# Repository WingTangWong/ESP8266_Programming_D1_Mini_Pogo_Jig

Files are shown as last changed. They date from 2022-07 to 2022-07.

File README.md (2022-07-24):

# ESP8266 Programming D1 Mini Pogo Jig V2

This board makes use of a WemosD1Mini (ESP8266 version) board as a USB->SERIAL adapter to flash
ESP-12 modules via POGO pins.

* [Eagle Files](EAGLE)
* [KiCAD Files](KICAD)
* [Gerber/Drill Production Files](PRODUCTION_FILES)
* [Gerber/Drill Production File ZIP](PRODUCTION_FILES/ESP12_Harness.zip)

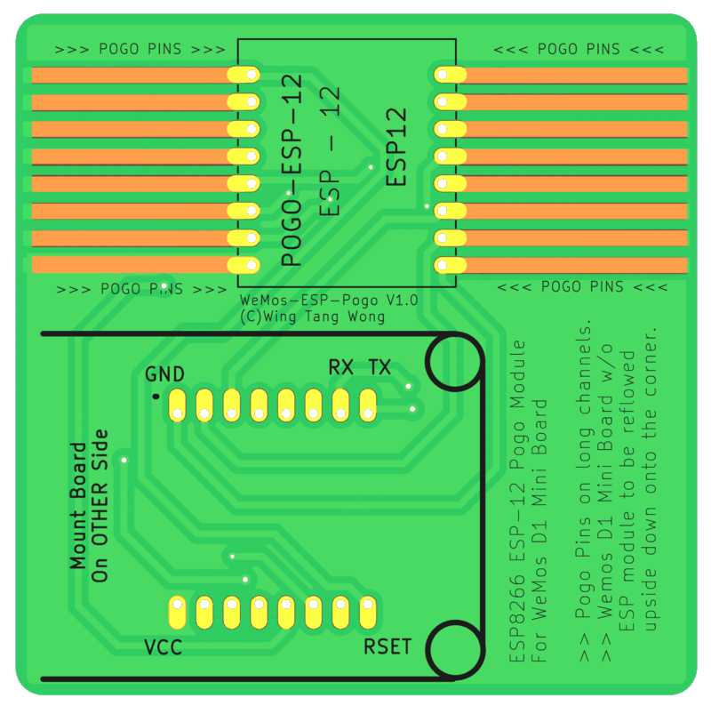
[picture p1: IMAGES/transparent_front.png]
Front

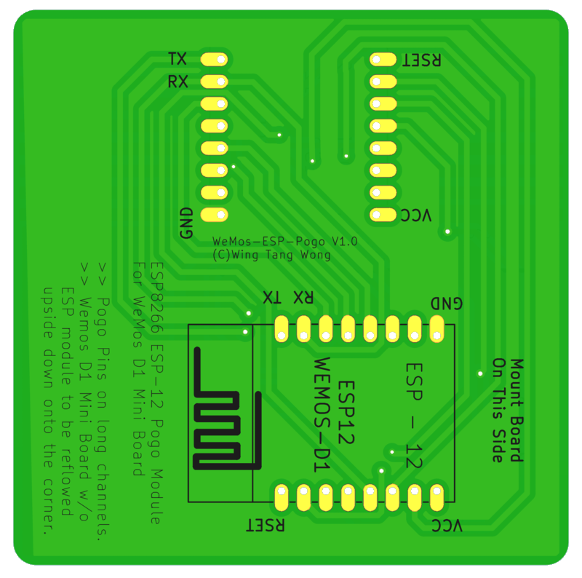
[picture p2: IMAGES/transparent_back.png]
Back


# Version 2 - Changelog

* Imported [Eagle CAD](EAGLE) files into [KiCAD 6.x](KICAD) and did some cleanup:
  * Rerouted some paths so that they weren't right on top of each other.
  * Fixed an import bug to make sure that the pogo traces show up.
  * Fixed the silkscreen on some footprints so that DRC passes without warnings.
* Exported Gerber and Drill files for the Version 2 design from KiCAD: [Production Files](PRODUCTION_FILES) / [Production File ZIP](PRODUCTION_FILES/ESP12_Harness.zip)

# Original Version 1 - Changelog

* Originally Designed in [Eagle CAD](EAGLE)
* Circuit works, but traces were pretty close together
* The masking configs don't port to KiCad very well, so creating a version 2 that is done using [KiCAD](KICAD)
* Silkscreens are all over the place. lulz.

This is a board designed to take a WeMos D1 Mini board(with the ESP module removed) and use it as a USB interface with built-in reset/flash
functionality for bare ESP8266 modules similar to the ESP-12 units.

The PCB was drawn up in Eagle and I have successfully gotten them manufactured through OshPark.

They are designed to be used with Pogo pins. I STRONGLY recommend the mushroom head type. 

The D1 Mini board is to be mated to the PCB in a manner similar to ball grid array: add solder to the pads where the ESP module was to give it a bump.

Rest the board on the PCB within the outline with the bumps facing their matching set of pads and heat from below with a hot air gun. When the solder
melts, the boards will come together. Presuming no bridges, you should be good to go.

# Gotchas

* Don't install the pogo pins too far in. Otherwise, you'll never get the ESP module installed.
* Don't get flux or solder onto the pin portion of the pogo pin... this will ruin them.
* Don't use low temp solder paste... tried this route and was a PITA.
* You can solder the pogo pins individually... but I had the best luck with 2 runs of solder paste on the end away from the pin side and placing the pins in place and using hot air to reflow the solder. This works great.

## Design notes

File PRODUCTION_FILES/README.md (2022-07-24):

# Gerber and Drill files for the ESP12 board.

* Generated from KiCAD files

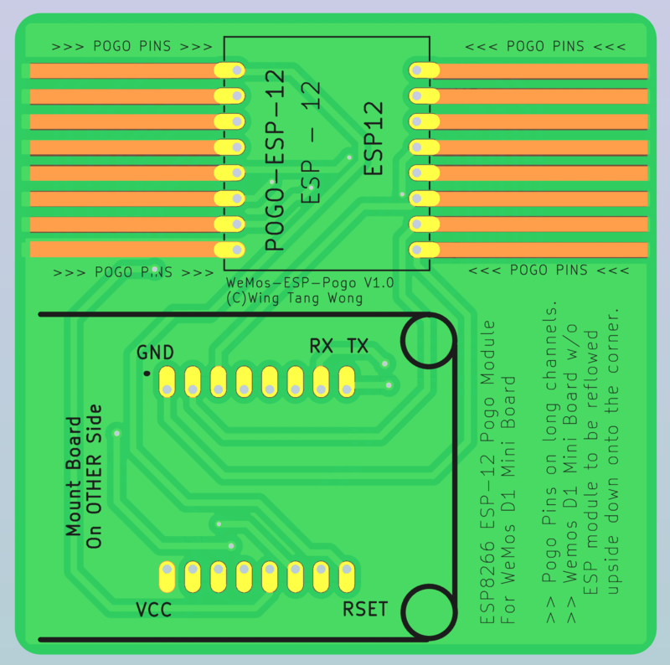
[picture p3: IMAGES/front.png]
PCB Front

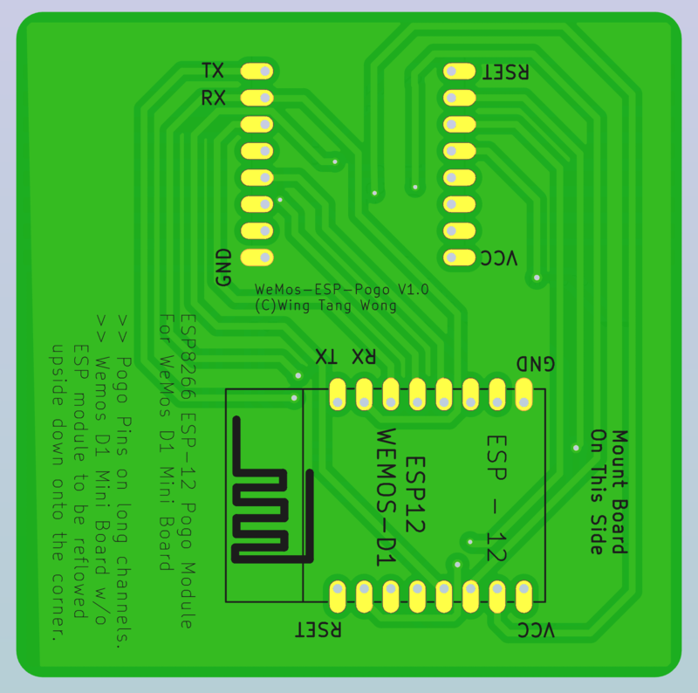
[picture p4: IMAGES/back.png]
PCB Back


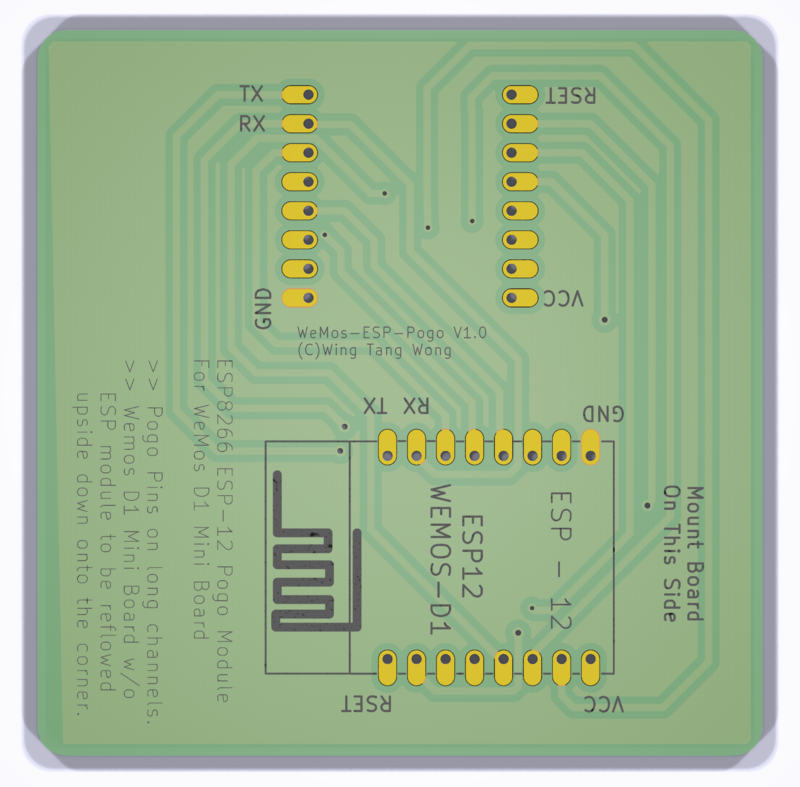
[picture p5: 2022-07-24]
IMAGES/back_3d.png

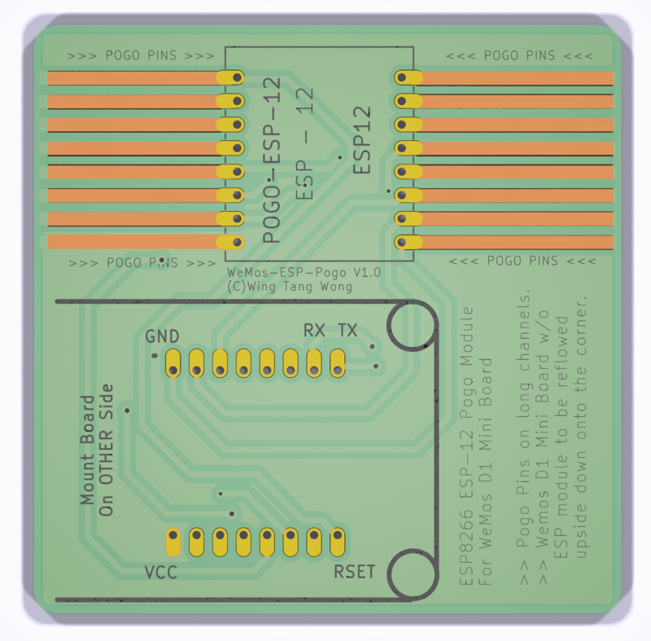
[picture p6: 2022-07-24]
IMAGES/front_3d.png

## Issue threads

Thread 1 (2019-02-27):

Gerber version of the board

adrianmihalko, 2019-02-27:
Somebody please can convet Eagle .brd file into Gerber project? Many PCB services are accepting only this format.

WingTangWong, 2022-07-24:
Hey hey, resolving this issue. I've been migrating other stuff to KiCad, finally got around to this one. You can find the Gerber and Drill files in the [Production Files folder.](https://github.com/WingTangWong/ESP8266_Programming_D1_Mini_Pogo_Jig/tree/main/PRODUCTION_FILES)

Closed 2022-07-24.

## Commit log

2017-02-26 Adding brd and sch files
    [ESP12_Harness.brd, ESP12_Harness.sch]
2022-07-24 Moved Eagle CAD files to their own folder
    [ESP12_Harness.brd, ESP12_Harness.sch]
2022-07-24 Adding rendered images of updated board.
2022-07-24 Adding production output files and images
    [ESP12_Harness-B_Cu.gbr, ESP12_Harness-B_Mask.gbr, ESP12_Harness-B_Paste.gbr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]
